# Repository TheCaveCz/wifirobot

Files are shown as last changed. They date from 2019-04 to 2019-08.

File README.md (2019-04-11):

# WiFi robot

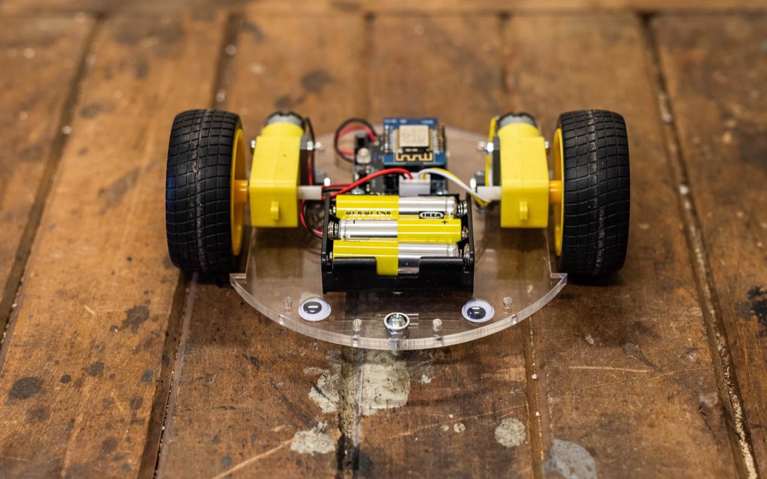
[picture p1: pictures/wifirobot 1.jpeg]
Wifirobot


ESP8266 chip on Wemos D1 mini module that is driving two DC geared motors using L293D chip. One WS2812 led for status, one tact switch for reset. Possibility of extending functionality via I2C bus.
Firmware contains Blynk platform integration for mobile app control. Can also be controlled using UDP packets.

More resources:
* [3D prints](stl)
* Firmware
  * [Original](firmware/robot) - uses [Arduino core for ESP8266](https://github.com/esp8266/Arduino), using [Blynk](https://blynk.cc) platform
  * [Tester](firmware/robot-test) - testing sketch
* [Hardware assembly](pictures)
* [PCB drawings](board) - created in EAGLE 9.2

## Setup

### On your computer

* Install [Arduino core for ESP8266](https://github.com/esp8266/Arduino#installing-with-boards-manager) - **use version 2.4.2 or above**
* Install the [Blynk Arduino library](http://help.blynk.cc/getting-started-library-auth-token-code-examples/how-to-install-blynk-library-for-arduino)
* Install the [WiFi Manager library](https://github.com/tzapu/WiFiManager)
* Compile and upload the [firmware](firmware/robot)

### On your mobile phone

* Install [Blynk app](https://www.blynk.cc/getting-started/)
* Create account or log in
* Create new empty project in Blynk App
* Copy auth token from the app or your email
* Connect to the robot AP
* Wait for WiFi login popup (or use browser and navigate to `http://192.168.4.1`)
* Enter WiFi credentials and auth token
* Setup the Blynk project (see next section)

### Reconfiguring or resetting robot

* Hold button until status LED lights up with violet color
* Connect to the robot AP
* Wait for WiFi login popup (or use browser and navigate to `http://192.168.4.1`)
* Enter WiFi credentials and auth token

## Blynk project

Total required energy: 1200

### Components

* Joystick
* Button
* zeRGBa
* Level H

Recommended layout:

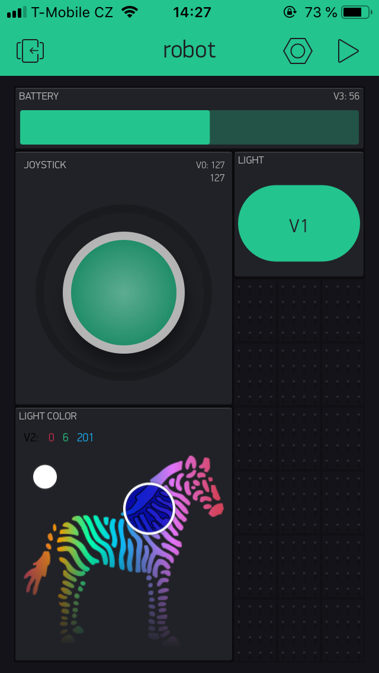
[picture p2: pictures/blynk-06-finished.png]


### Component settings

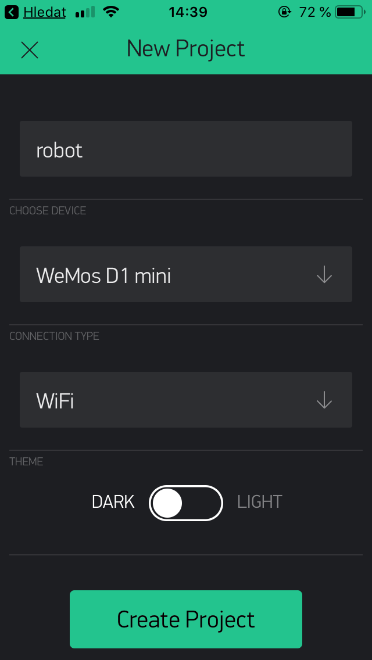
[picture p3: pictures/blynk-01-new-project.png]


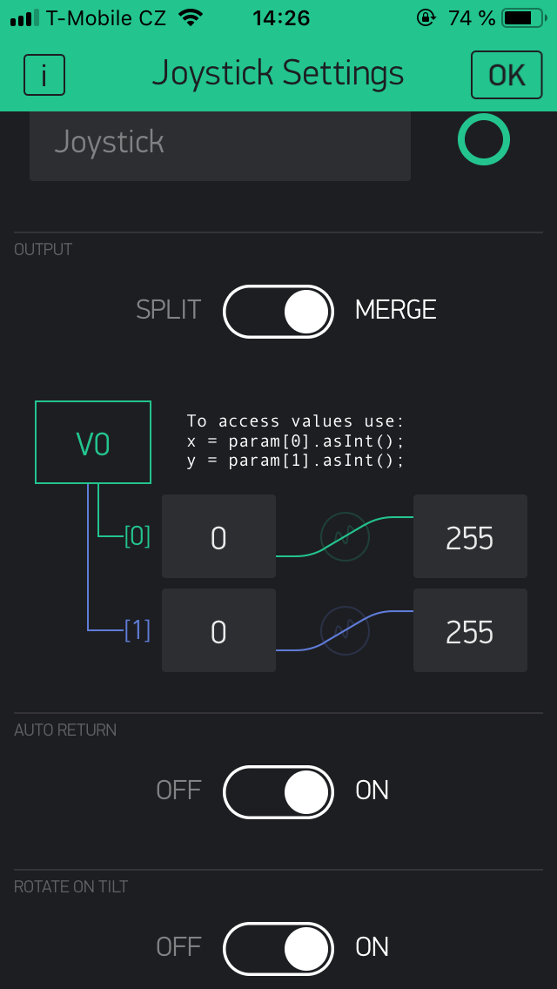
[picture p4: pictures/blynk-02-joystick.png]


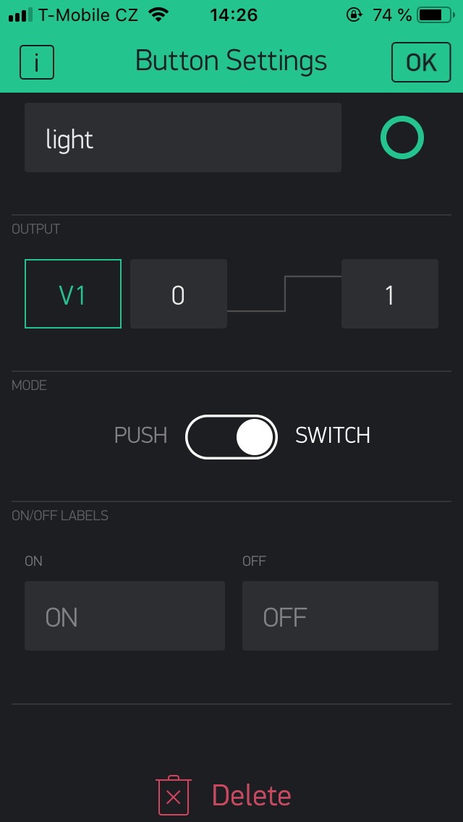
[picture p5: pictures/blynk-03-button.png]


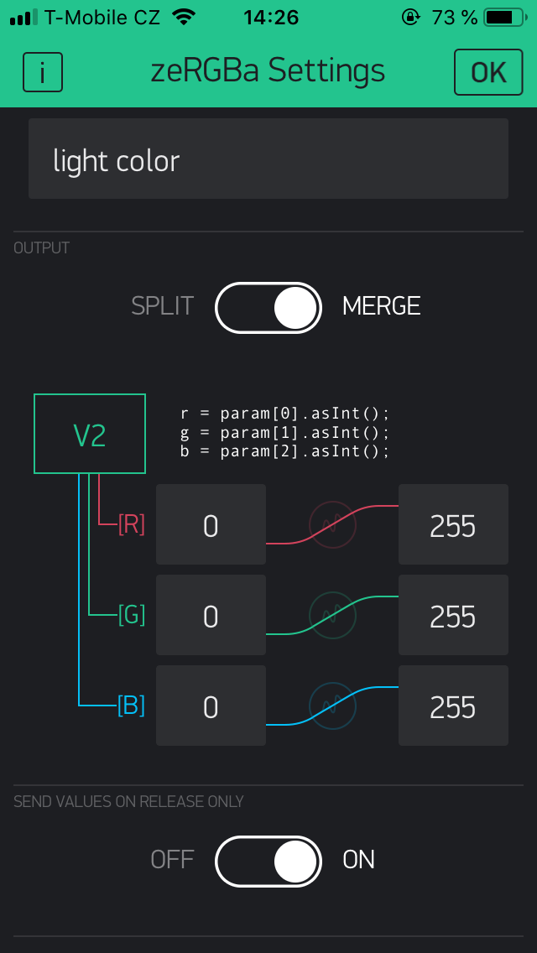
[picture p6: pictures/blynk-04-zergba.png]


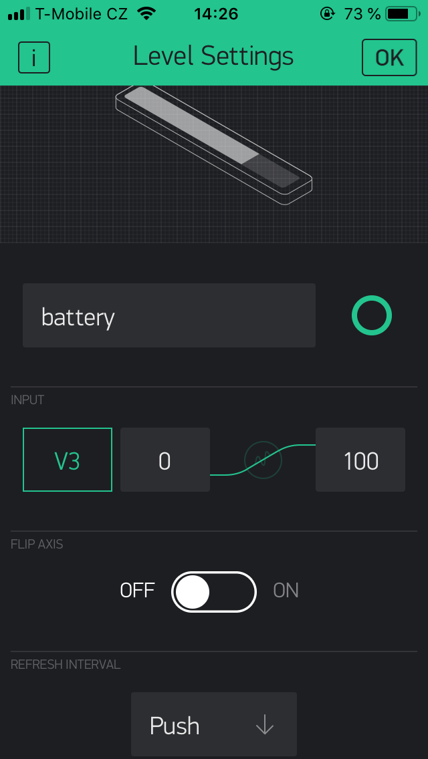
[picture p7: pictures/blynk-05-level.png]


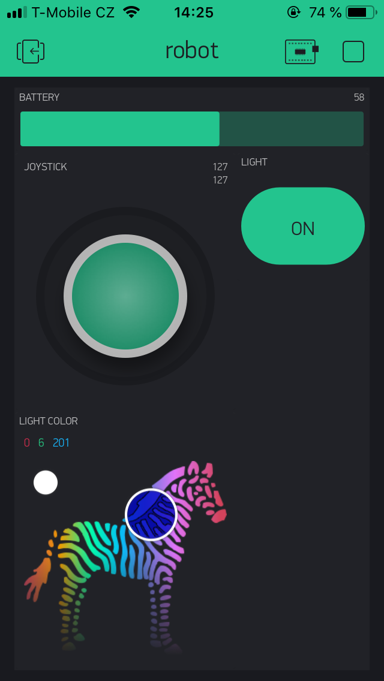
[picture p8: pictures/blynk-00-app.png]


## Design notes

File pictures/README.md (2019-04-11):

# Assembly instructions

PDF with all instructions in one file: [wifirobot.pdf](wifirobot.pdf)

assembly
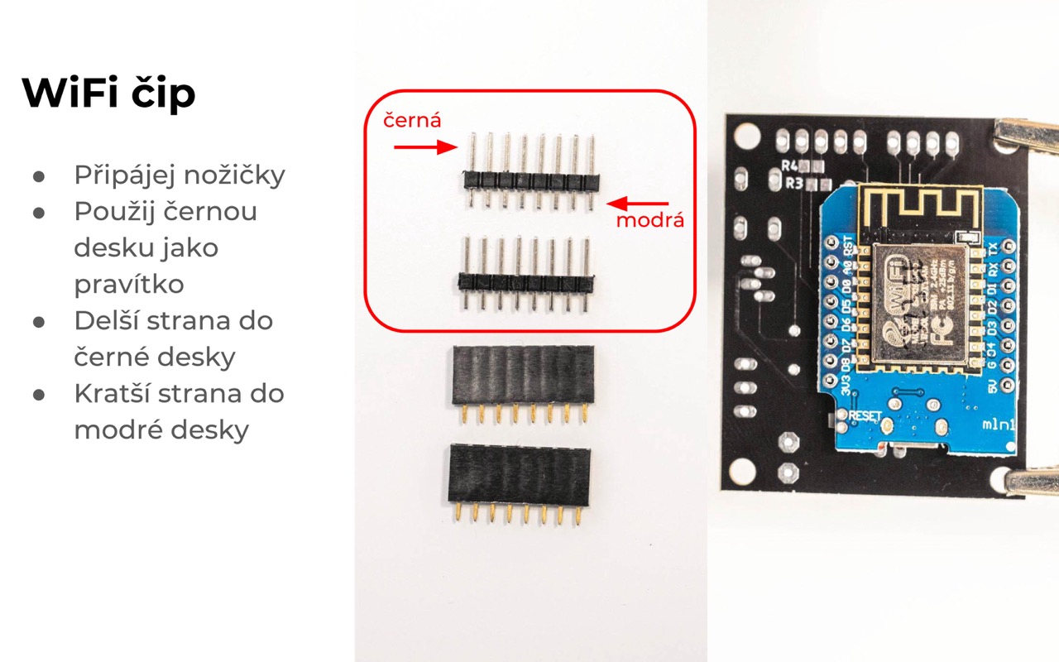
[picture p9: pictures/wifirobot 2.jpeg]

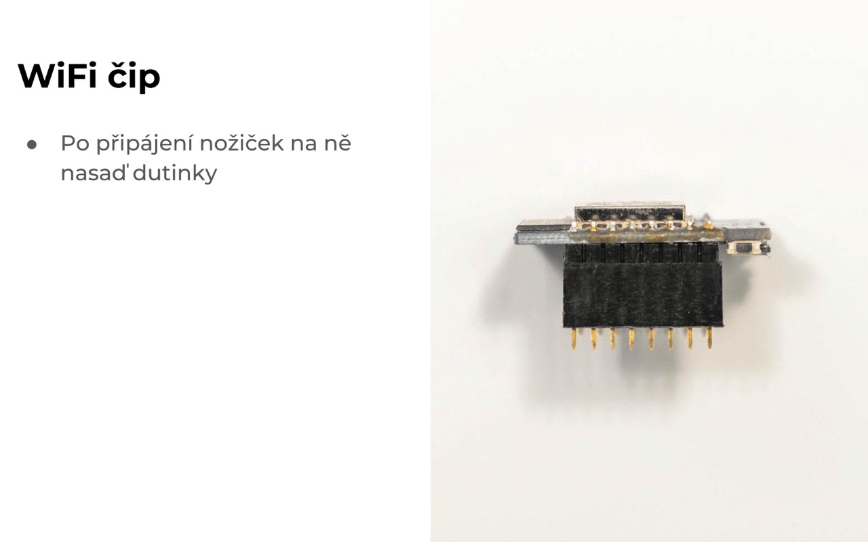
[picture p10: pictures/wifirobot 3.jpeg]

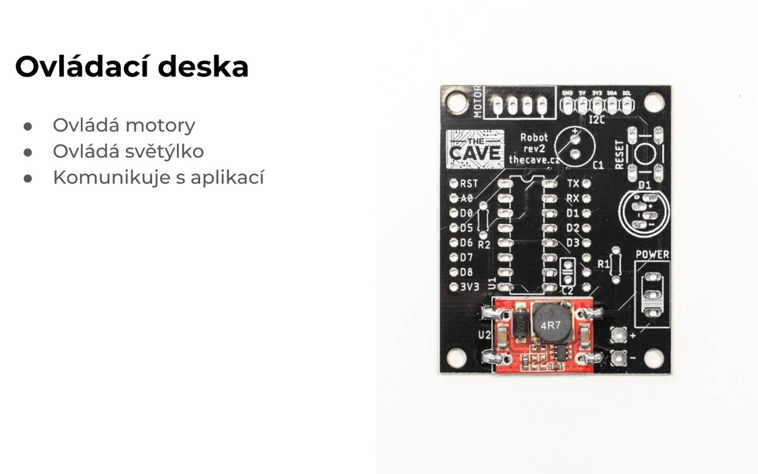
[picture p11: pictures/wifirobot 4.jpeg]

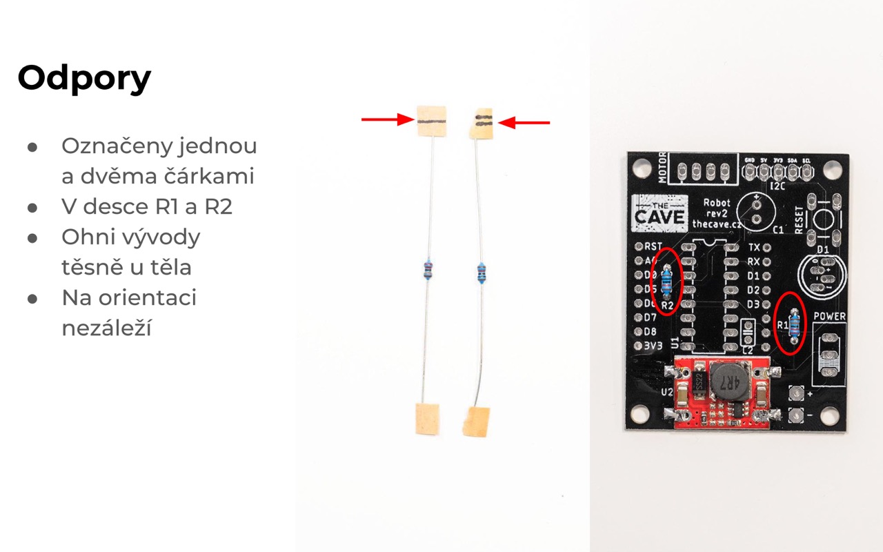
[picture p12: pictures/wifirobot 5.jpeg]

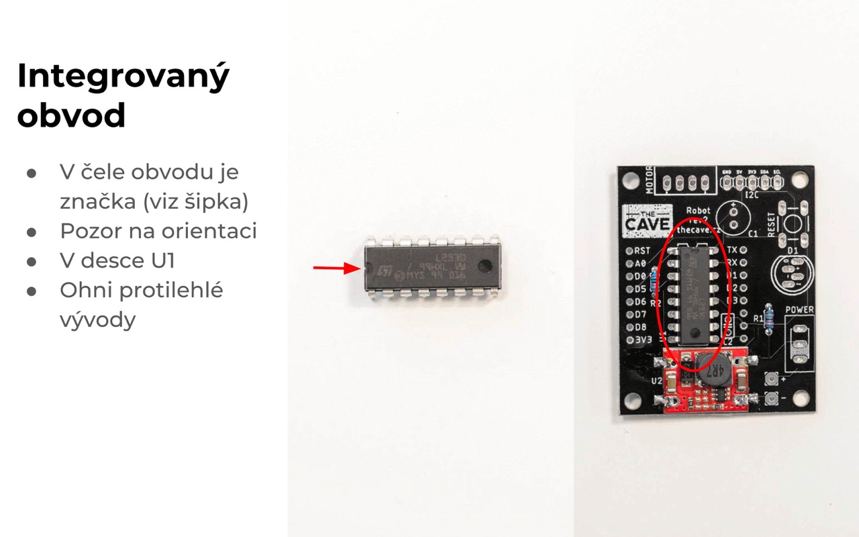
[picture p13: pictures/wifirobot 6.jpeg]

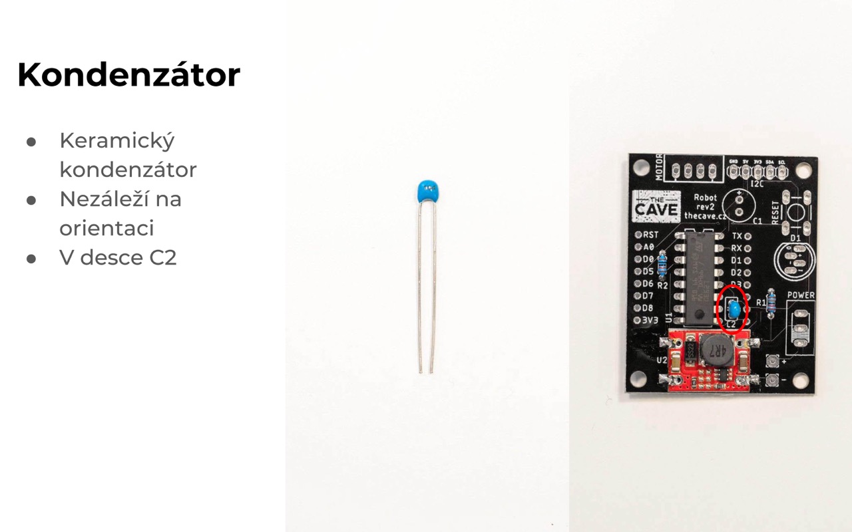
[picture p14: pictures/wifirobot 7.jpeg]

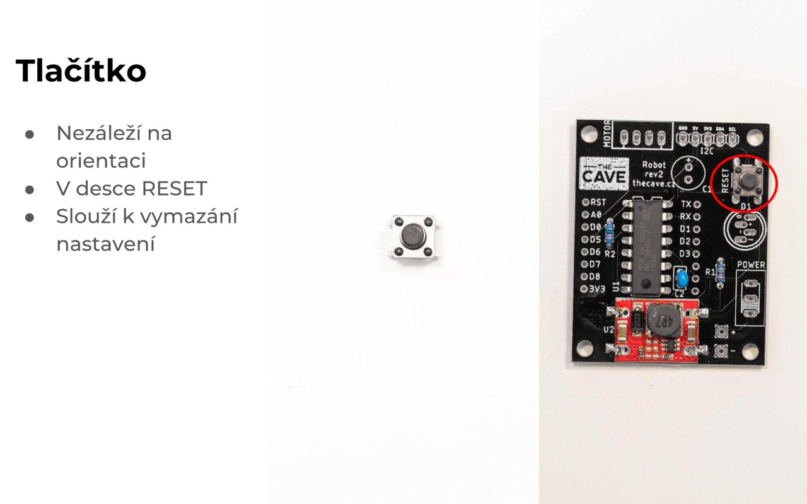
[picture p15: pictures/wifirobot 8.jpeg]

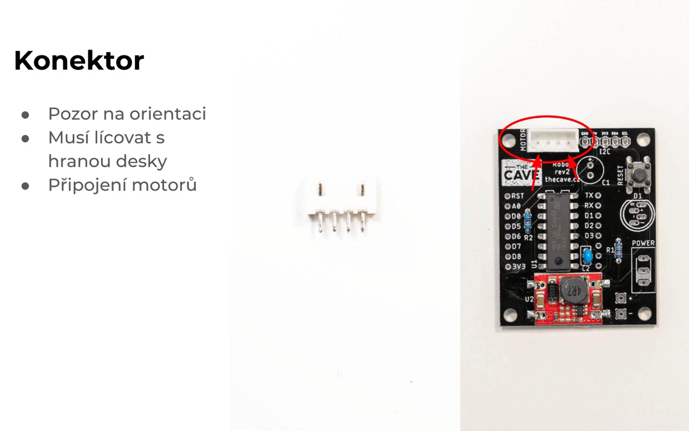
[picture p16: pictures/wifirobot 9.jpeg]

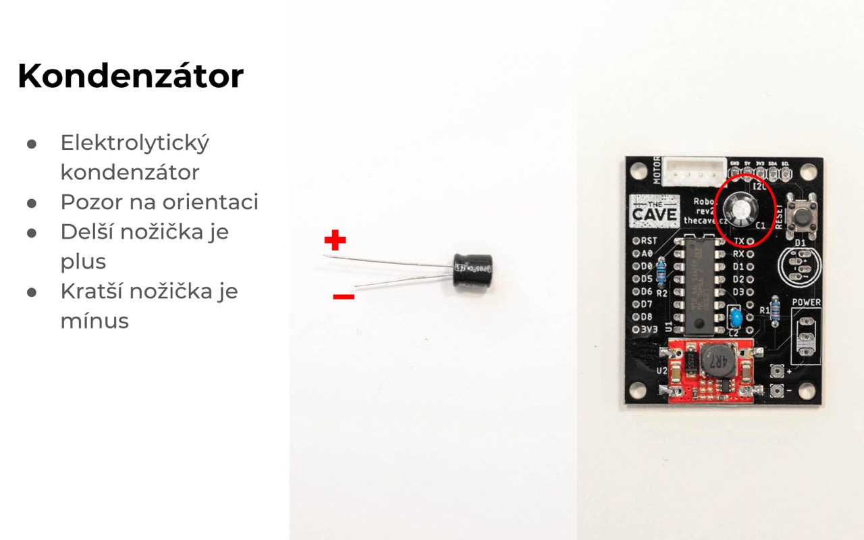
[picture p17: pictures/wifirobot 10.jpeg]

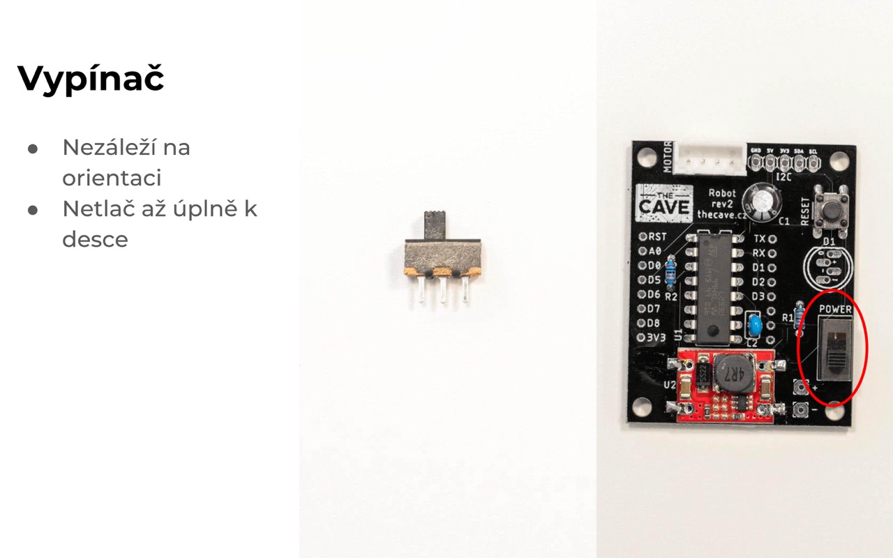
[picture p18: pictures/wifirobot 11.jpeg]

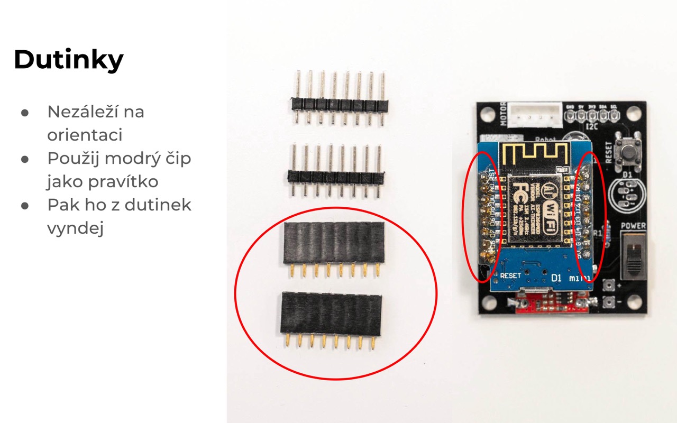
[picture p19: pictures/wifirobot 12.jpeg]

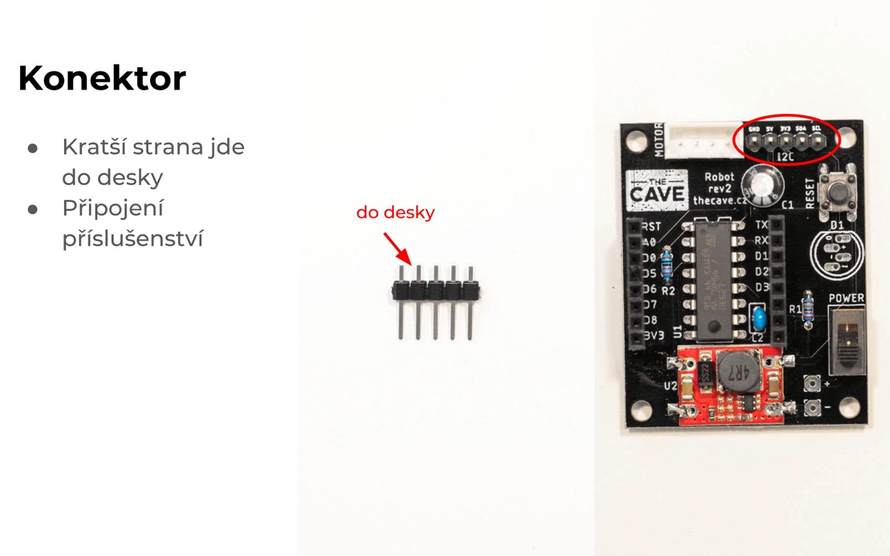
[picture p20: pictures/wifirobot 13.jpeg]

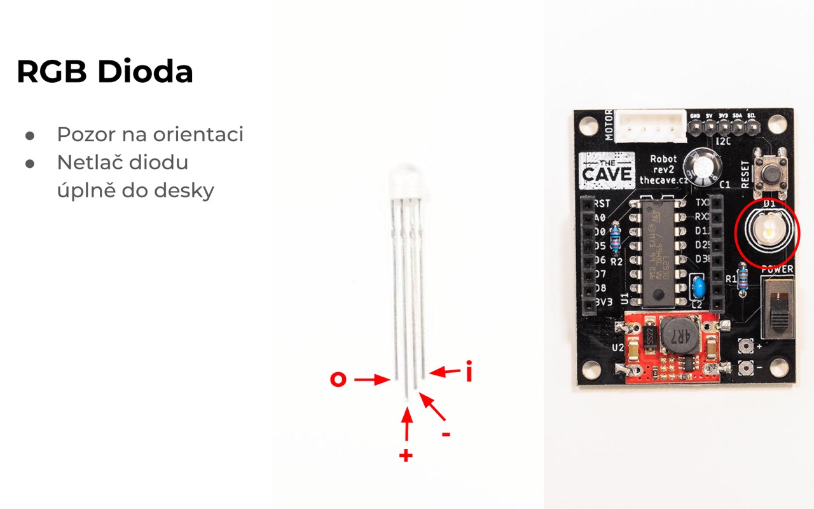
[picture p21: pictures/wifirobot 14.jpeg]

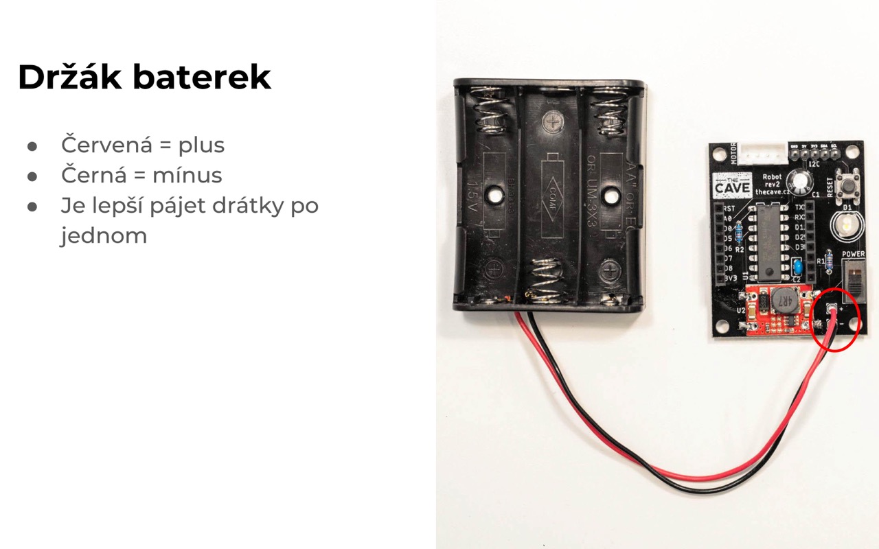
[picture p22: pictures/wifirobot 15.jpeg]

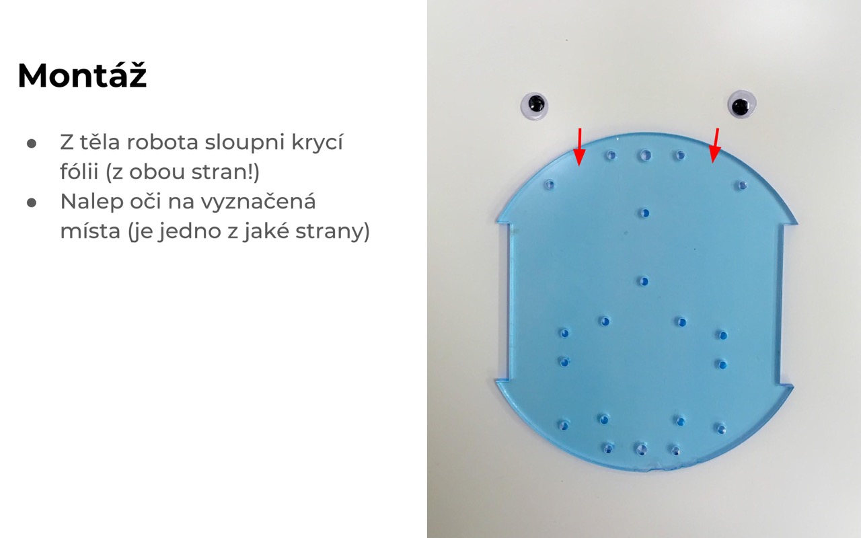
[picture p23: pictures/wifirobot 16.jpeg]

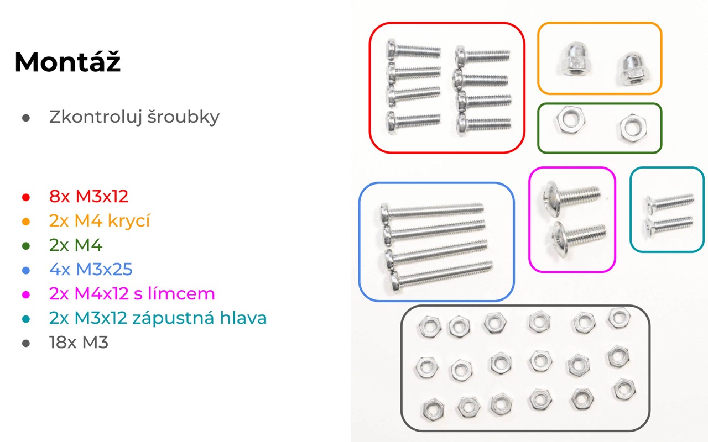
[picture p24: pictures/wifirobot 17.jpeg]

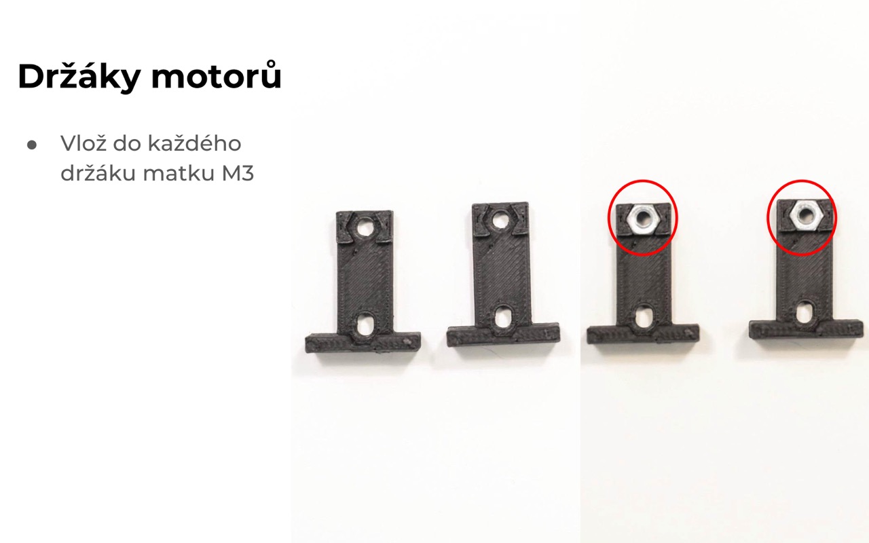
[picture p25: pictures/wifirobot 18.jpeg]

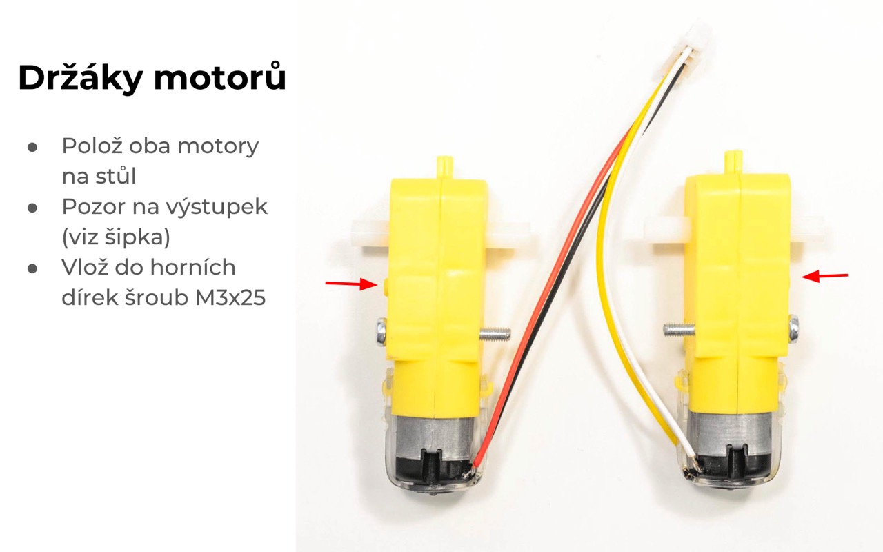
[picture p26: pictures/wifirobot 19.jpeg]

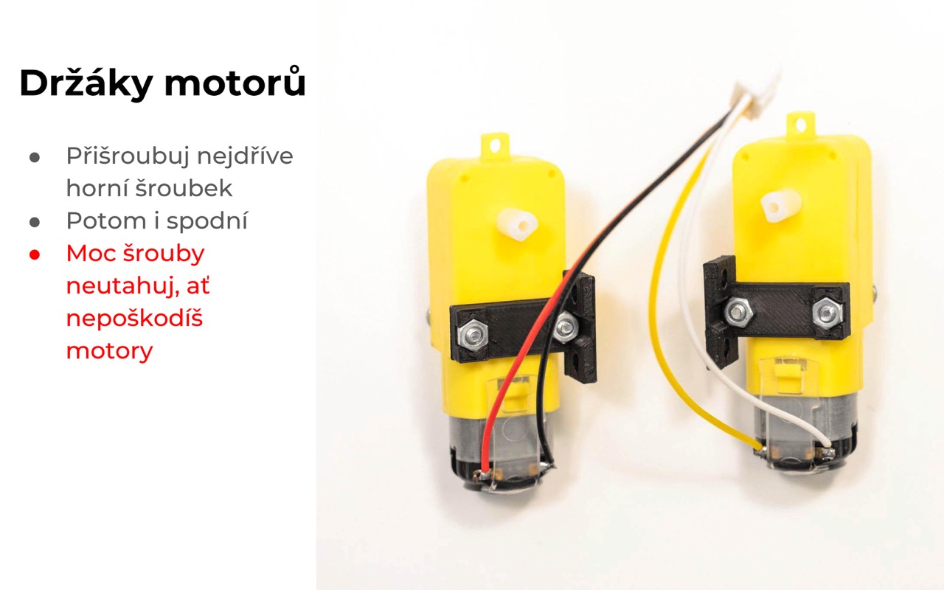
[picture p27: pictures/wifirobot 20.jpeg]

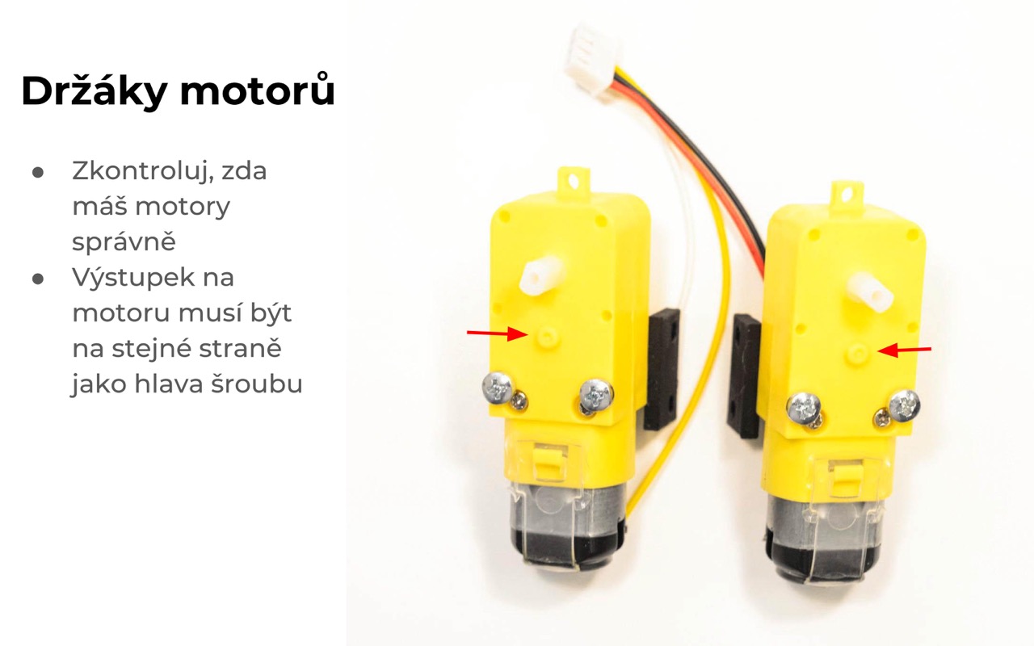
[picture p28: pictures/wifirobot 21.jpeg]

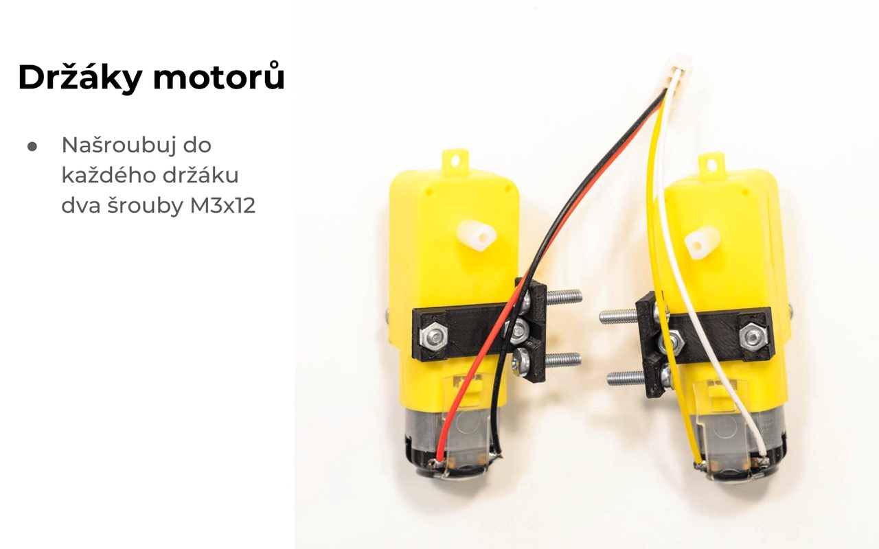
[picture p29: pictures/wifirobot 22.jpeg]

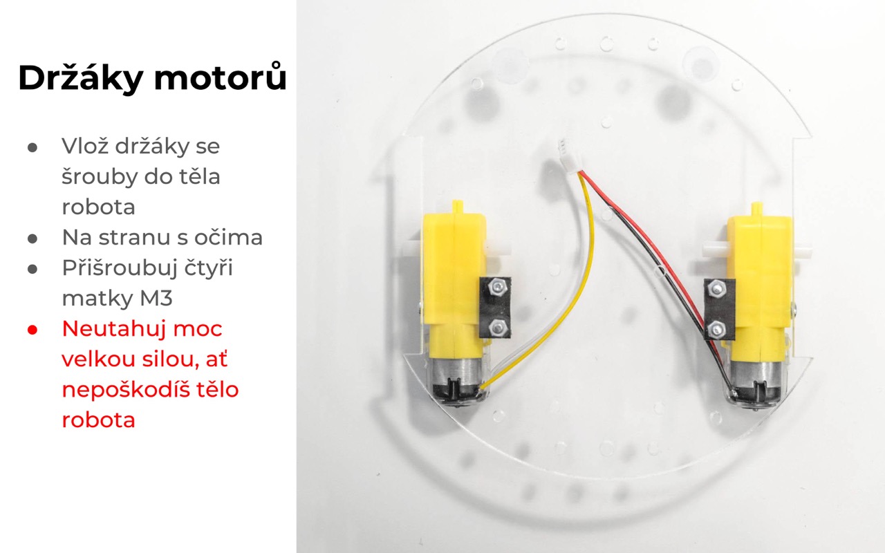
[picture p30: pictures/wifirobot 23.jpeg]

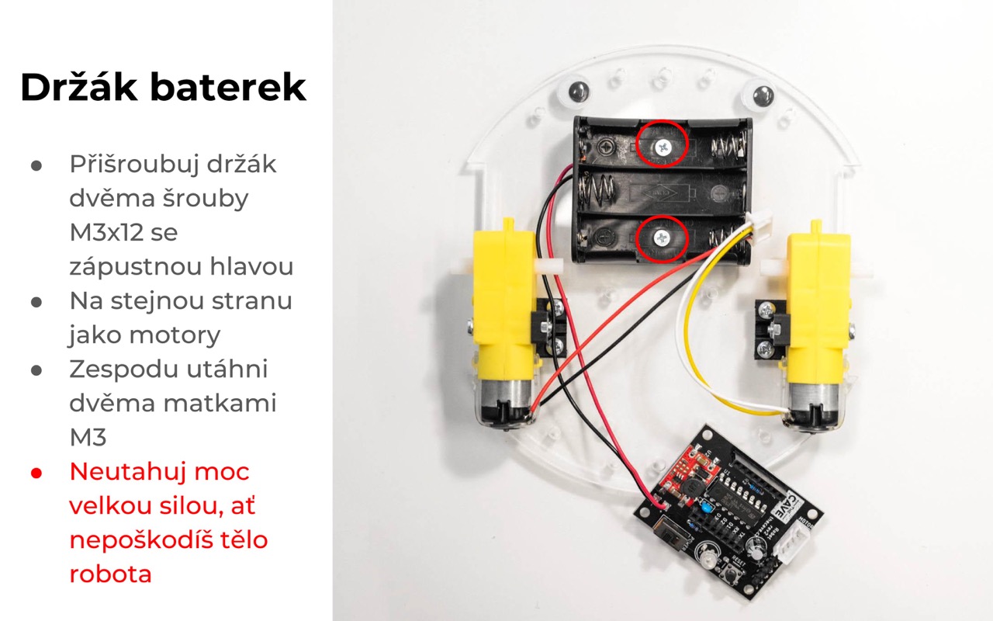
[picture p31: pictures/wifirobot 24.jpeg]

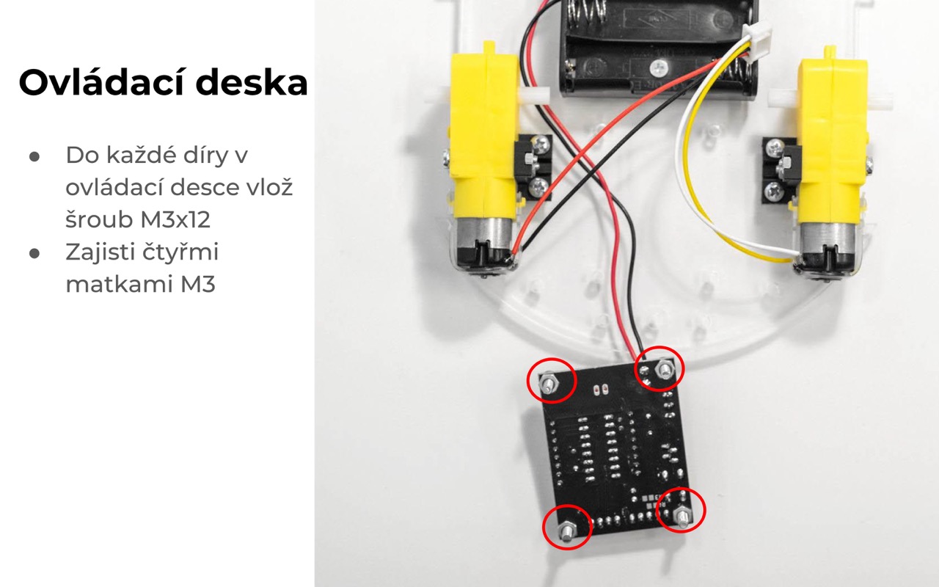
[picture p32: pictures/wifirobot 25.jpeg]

assembly
assembly
assembly
assembly
assembly

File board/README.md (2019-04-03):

# Board

Schematic

PCB

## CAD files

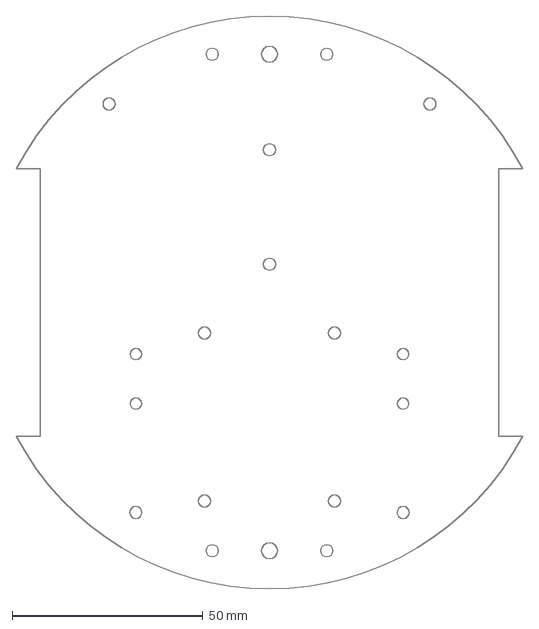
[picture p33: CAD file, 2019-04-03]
drawings/robot.dxf
132.7 x 150.0 mm

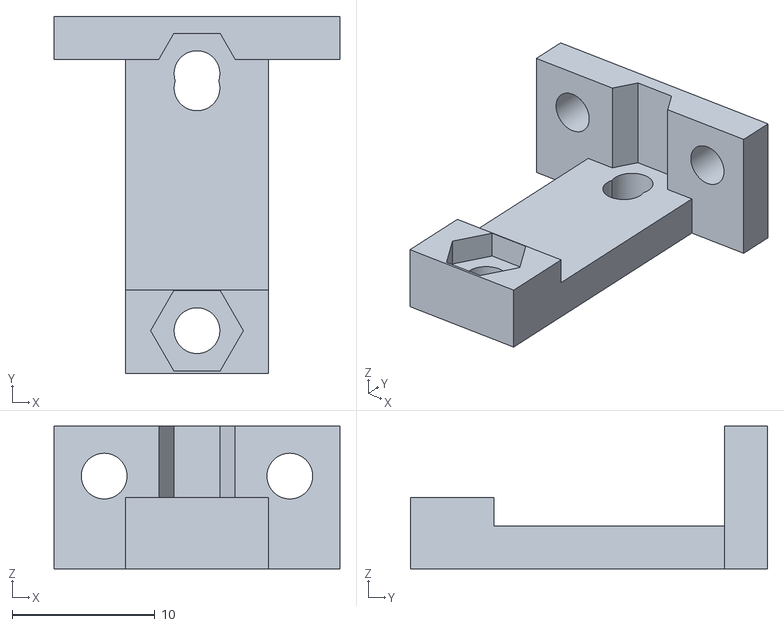
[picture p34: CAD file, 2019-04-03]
stl/motor.stl
20.0 x 25.0 x 10.0

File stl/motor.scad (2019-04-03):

//
//  WifiRobot
//  motor holder
//
//  The Cave, 2019
//  https://thecave.cz
//
//  Licensed under MIT License (see LICENSE file for details)
//

$fn = 100;
$wall = 3;
$width = 20;
$width2 = 10;
$step = 6;
$stepHeight = 7;
$height = 25;
$len = 7;
$offset = $len/2;
$nut=6.5;

rotate([90,0,0])
difference() {
    union() {
        translate([($width-$width2)/2,0,0]) {
            cube([$width2,$wall,$height]);
            translate([0,0,$height-$nut*0.9]) cube([$width2,$wall+2,$nut*0.9]);
        }
        cube([$width,$len+$wall,$wall]);
    }

    translate([10,$wall+$len+1,4]) #rotate([90,0,0]) {
        cylinder(d=3.2,h=20);
        translate([0,1,0]) cylinder(d=3.2,h=20); // some motors have 17mm hole distance instead of 18
        cylinder(d=$nut,h=$len+1,$fn=6);
    }
    
    translate([10,$wall+$len+1,4+18]) #rotate([90,0,0]) {
        cylinder(d=3.2,h=20);
        cylinder(d=$nut,h=$len+1,$fn=6);
    }
    
    translate([($width-$step)/4,$wall+$offset,-16]) {
        #cylinder(d=3.2,h=20);
        translate([0,0,20]) #cylinder(d=6,h=3);
    }
    translate([($width-$step)/4*3+$step,$wall+$offset,-16]) {
        #cylinder(d=3.2,h=20);
        translate([0,0,20]) #cylinder(d=6,h=3);
    }
}

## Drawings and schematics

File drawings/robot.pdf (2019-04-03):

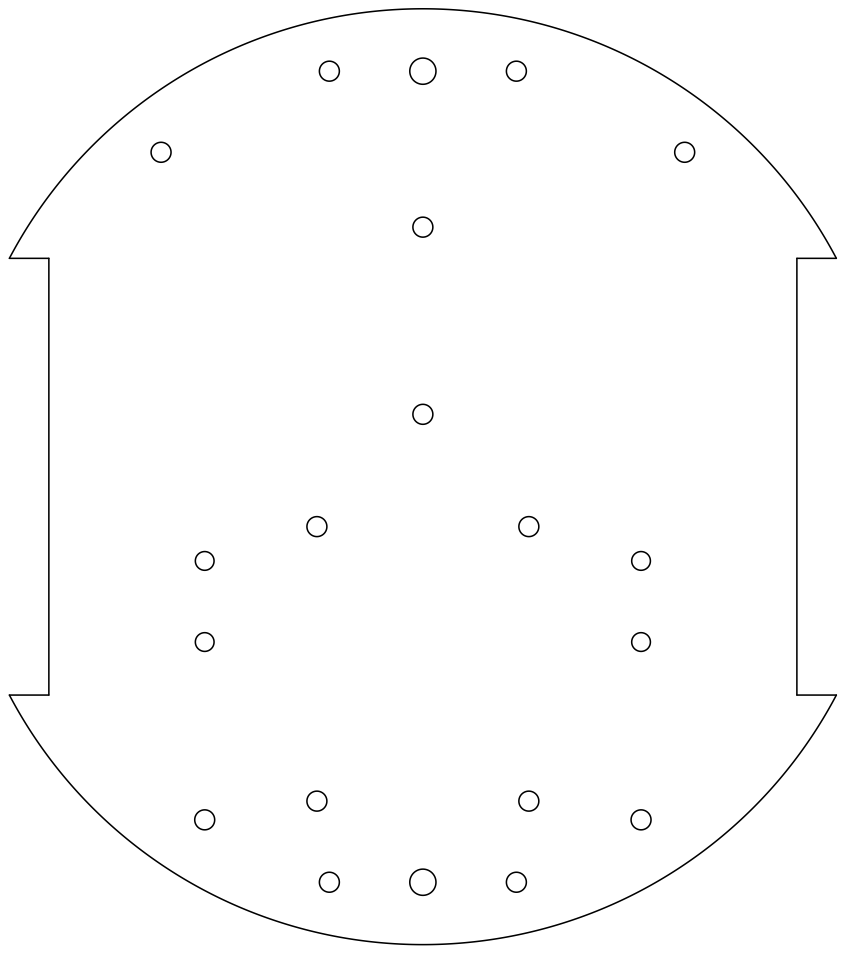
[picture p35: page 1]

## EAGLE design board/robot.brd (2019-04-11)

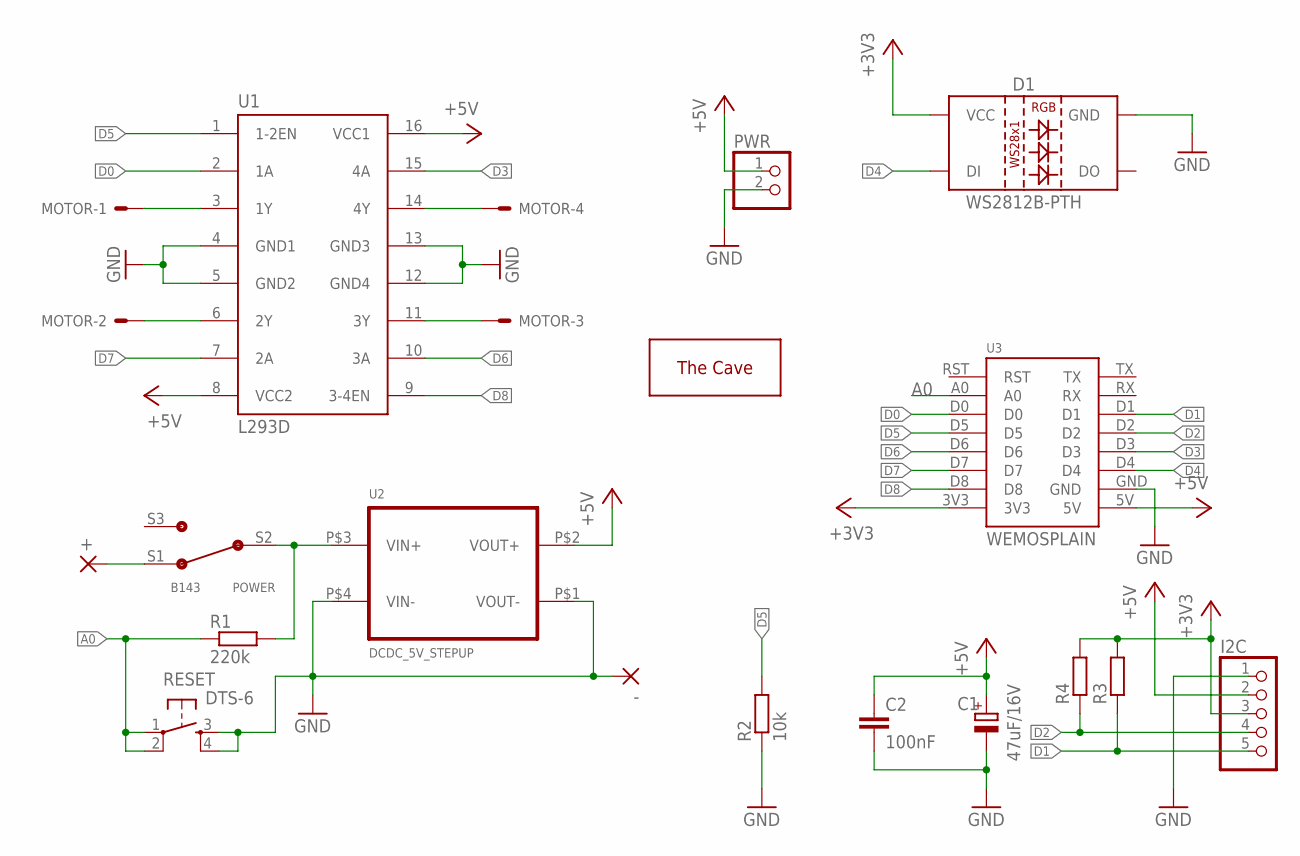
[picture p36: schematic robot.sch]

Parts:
+: 2,54/0,8
-: 2,54/0,8
C1: 47uF/16V; E2,5-7
C2: 100nF; C025-025X050
D1: WS2812B-PTH; WS2812B-PTH-KIT
I2C: PINHD-1X5; 1X05
MOTOR: JST-XH-04-PIN-LONG-PAD; JST-XH-04-PACKAGE-LONG-PAD
POWER: B143
PWR: PINHD-1X2; 1X02
R1: 220k; 0204/5
R2: 10k; 0204/5
R3, R4: R-EU_R0805; R0805
RESET: DTS-6
U1: L293D; DIL16
U2: DCDC_5V_STEPUP
U3: WEMOSPLAIN; WEMOS-PLAIN
U$1: THECAVE_LOGO_NEW_TOP_SMALL; NEW_LOGO_SMALL_TOP

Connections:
+3V3: D1.3-VCC (VCC), I2C.3, R3.2, R4.2, U3.3V3
+5V: C1.+, C2.1, I2C.2, PWR.1, U1.8 (VCC2), U1.16 (VCC1), U2.P$2 (VOUT+), U3.5V
A0: R1.1, RESET.1, RESET.2, U3.A0
D0: U1.2 (1A), U3.D0
D1: I2C.5, R3.1, U3.D1
D2: I2C.4, R4.1, U3.D2
D3: U1.15 (4A), U3.D3
D4: D1.1-IN (DI), U3.D4
D5: R2.2, U1.1 (1-2EN), U3.D5
D6: U1.10 (3A), U3.D6
D7: U1.7 (2A), U3.D7
D8: U1.9 (3-4EN), U3.D8
GND: -.1, C1.-, C2.2, D1.2-GND (GND), I2C.1, PWR.2, R2.1, RESET.3, RESET.4, U1.4 (GND1), U1.5 (GND2), U1.12 (GND4), U1.13 (GND3), U2.P$1 (VOUT-), U2.P$4 (VIN-), U3.GND
unnamed: MOTOR.1, U1.3 (1Y)
unnamed: MOTOR.2, U1.6 (2Y)
unnamed: MOTOR.3, U1.11 (3Y)
unnamed: MOTOR.4, U1.14 (4Y)
unnamed: POWER.S2 (COM), R1.2, U2.P$3 (VIN+)
unnamed: +.1, POWER.S1

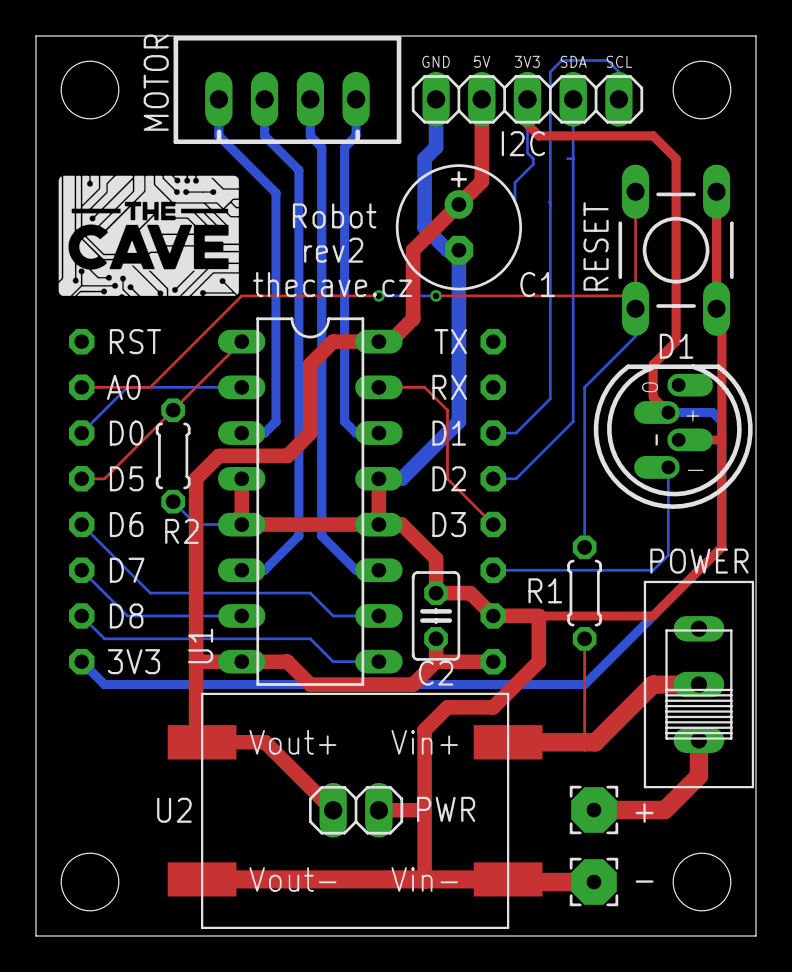
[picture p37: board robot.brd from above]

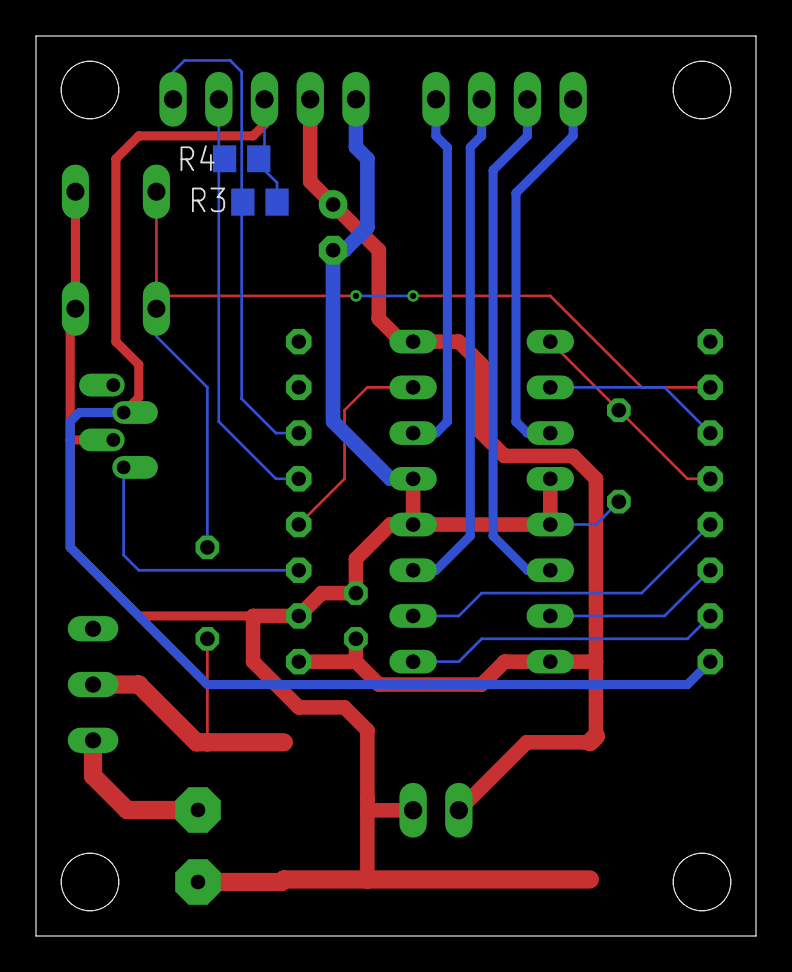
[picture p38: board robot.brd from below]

Board: 2 copper layers, 40.0 x 50.0 mm, 18 parts (2 on the bottom side), 19 nets.

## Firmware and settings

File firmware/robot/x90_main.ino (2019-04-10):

void setup() {
  Serial.begin(115200);

  logInfo("Starting");
  logValue("Chip id: ", chipId);

  pixelsSetup();
  configSetup();
  motorsSetup();
  adcSetup();
  otaSetup();
  logicSetup();
  controlSetup();
  wifiSetup();
  blynkSetup();
  logInfo("Ready to go!");
}

void loop() {
  ArduinoOTA.handle();
  blynkTick();
  adcTick();
  motorsTick();
  controlTick();
}

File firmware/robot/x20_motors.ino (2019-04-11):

#define MOTORS_ACCEL_PER_TICK 60
#define MOTORS_TICK 20UL

#define MOTORS_MAX 255
#define MOTORS_MIDDLE 127

int16_t m1speed;
int16_t m2speed;
int16_t m1targetSpeed;
int16_t m2targetSpeed;

uint32_t motorsTime;

uint16_t motorsSpeedToPwm(uint16_t speed) {
  if (speed == MOTORS_MIDDLE) {
    return 0;
  } else if (speed > MOTORS_MIDDLE) {
    return map(speed, MOTORS_MIDDLE, MOTORS_MAX, PWMRANGE / 1.5, PWMRANGE);
  } else {
    return map(speed, MOTORS_MIDDLE - 1, 0, PWMRANGE / 1.5, PWMRANGE);
  }
}

void motorsTick() {
  if (millis() < motorsTime) {
    return;
  }
  motorsTime = millis() + MOTORS_TICK;

  int delta = constrain(m1targetSpeed - m1speed, -MOTORS_ACCEL_PER_TICK, MOTORS_ACCEL_PER_TICK);
  m1speed += delta;
  delta = constrain(m2targetSpeed - m2speed, -MOTORS_ACCEL_PER_TICK, MOTORS_ACCEL_PER_TICK);
  m2speed += delta;

  digitalWrite(PIN_M1_A, m1speed > MOTORS_MIDDLE);
  digitalWrite(PIN_M1_B, m1speed < MOTORS_MIDDLE);
  analogWrite(PIN_M1_EN, motorsSpeedToPwm(m1speed));

  digitalWrite(PIN_M2_A, m2speed > MOTORS_MIDDLE);
  digitalWrite(PIN_M2_B, m2speed < MOTORS_MIDDLE);
  analogWrite(PIN_M2_EN, motorsSpeedToPwm(m2speed));
}

void motorsDisable() {
  pinMode(PIN_M1_EN, INPUT);
  pinMode(PIN_M2_EN, INPUT);
}

void motorsSetup() {
  analogWriteFreq(20000);

  pinMode(PIN_M1_A, OUTPUT);
  pinMode(PIN_M1_B, OUTPUT);
  pinMode(PIN_M1_EN, OUTPUT);

  pinMode(PIN_M2_A, OUTPUT);
  pinMode(PIN_M2_B, OUTPUT);
  pinMode(PIN_M2_EN, OUTPUT);

  m1speed = MOTORS_MIDDLE;
  m1targetSpeed = MOTORS_MIDDLE;
  m2speed = MOTORS_MIDDLE;
  m2targetSpeed = MOTORS_MIDDLE;
  motorsTime = 0;

  motorsTick();
}

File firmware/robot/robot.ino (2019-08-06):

/*
 * WifiRobot firmware for Blynk app
 * 
 * The Cave, 2019
 * https://thecave.cz
 * 
 * Licensed under MIT License (see LICENSE file for details)
 * 
 * board: LOLIN(WEMOS) D1 R2 & mini
 * 
 */
#define BLYNK_PRINT Serial
#define BLYNK_NO_FANCY_LOGO

#include <ESP8266WiFi.h>
#include <BlynkSimpleEsp8266.h>
#include <ESP8266mDNS.h>
#include <ArduinoOTA.h>
#include <WiFiManager.h>
#include <Ticker.h>
#include <EEPROM.h>
#include "ws2812.h"


// Firmware updates over-the-air will require admin password.
//#define OTA_PASSWORD "mySecretPassword"

// Serial port logging
#define LOG_ENABLED 1


#define BLYNK_JOYSTICK_PIN V0
#define BLYNK_LIGHT_PIN V1
#define BLYNK_RGB_PIN V2
#define BLYNK_BATTERY_PERCENT_PIN V3
#define BLYNK_BATTERY_VOLTAGE_PIN V4
#define BLYNK_M1_SPEED_PIN V5
#define BLYNK_M2_SPEED_PIN V6
#define BLYNK_BRAKE_PIN V7


#define PIN_M1_A D7
#define PIN_M1_B D0
#define PIN_M1_EN D5

#define PIN_M2_A D3
#define PIN_M2_B D6
#define PIN_M2_EN D8

#define HOSTNAME_PREFIX "robot-"

#define TIMEOUT_INTERVAL 20000UL
#define RECONNECT_INTERVAL 60000UL

#define UDP_PORT 44432

String chipId = String(ESP.getChipId(),HEX);

void keep_me_here() {} // must be present for Arduino IDE function prototype injection

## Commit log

2019-04-03 Add board and dxf drawing
    [robot.brd, robot.dxf, robot.sch]
2019-04-03 Add prints
    [motor.scad, motor.stl]
2019-04-11 Add capacitor values
    [robot.brd, robot.sch]
2019-04-11 Add motor speed pins
2019-08-06 [FW] Add brake pin
